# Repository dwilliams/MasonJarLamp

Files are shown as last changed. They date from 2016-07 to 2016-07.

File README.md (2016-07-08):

# MasonJarLamp
Making a board to turn a mason jar into an LED lamp

This lamp runs on 12V AC or DC.  The design is intended to be compatible with the 12V AC Garden Lighting systems available at hardware stores.



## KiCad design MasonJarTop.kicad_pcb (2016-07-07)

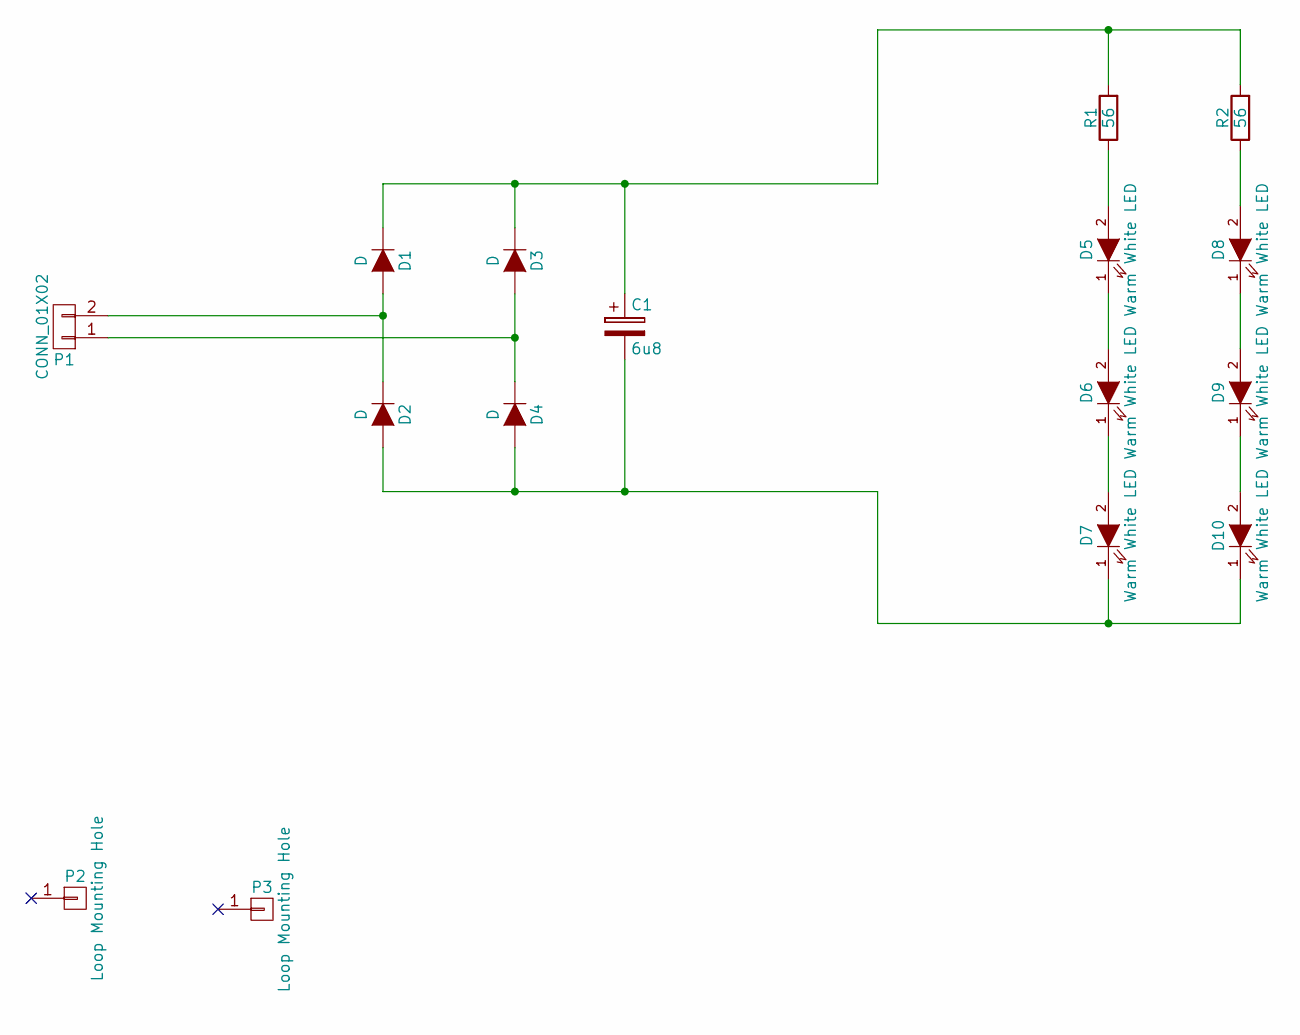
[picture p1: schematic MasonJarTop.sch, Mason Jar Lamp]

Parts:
C1: 6u8; c_elec_4x5.3; DigiKey 732-8429-1-ND
D1, D2, D3, D4: D; LED_1206; DigiKey DA2JF2300LCT-ND
D5, D6, D7, D8, D9, D10: Warm White LED; LED_1206; DigiKey 1416-1216-1-ND
P1: CONN_01X02; Pin_Header_Straight_1x02
P2, P3: Loop Mounting Hole; SolderWirePad_single_2mmDrill
R1, R2: 56; R_1206_HandSoldering; DigiKey 311-56ERCT-ND

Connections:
unnamed: C1.1, D1.1 (K), D3.1 (K), R1.2, R2.2
unnamed: C1.2, D2.2 (A), D4.2 (A), D7.1 (K), D10.1 (K)
unnamed: D1.2 (A), D2.1 (K), P1.2
unnamed: D3.2 (A), D4.1 (K), P1.1
unnamed: D5.1 (K), D6.2 (A)
unnamed: D5.2 (A), R1.1
unnamed: D6.1 (K), D7.2 (A)
unnamed: D8.1 (K), D9.2 (A)
unnamed: D8.2 (A), R2.1
unnamed: D9.1 (K), D10.2 (A)

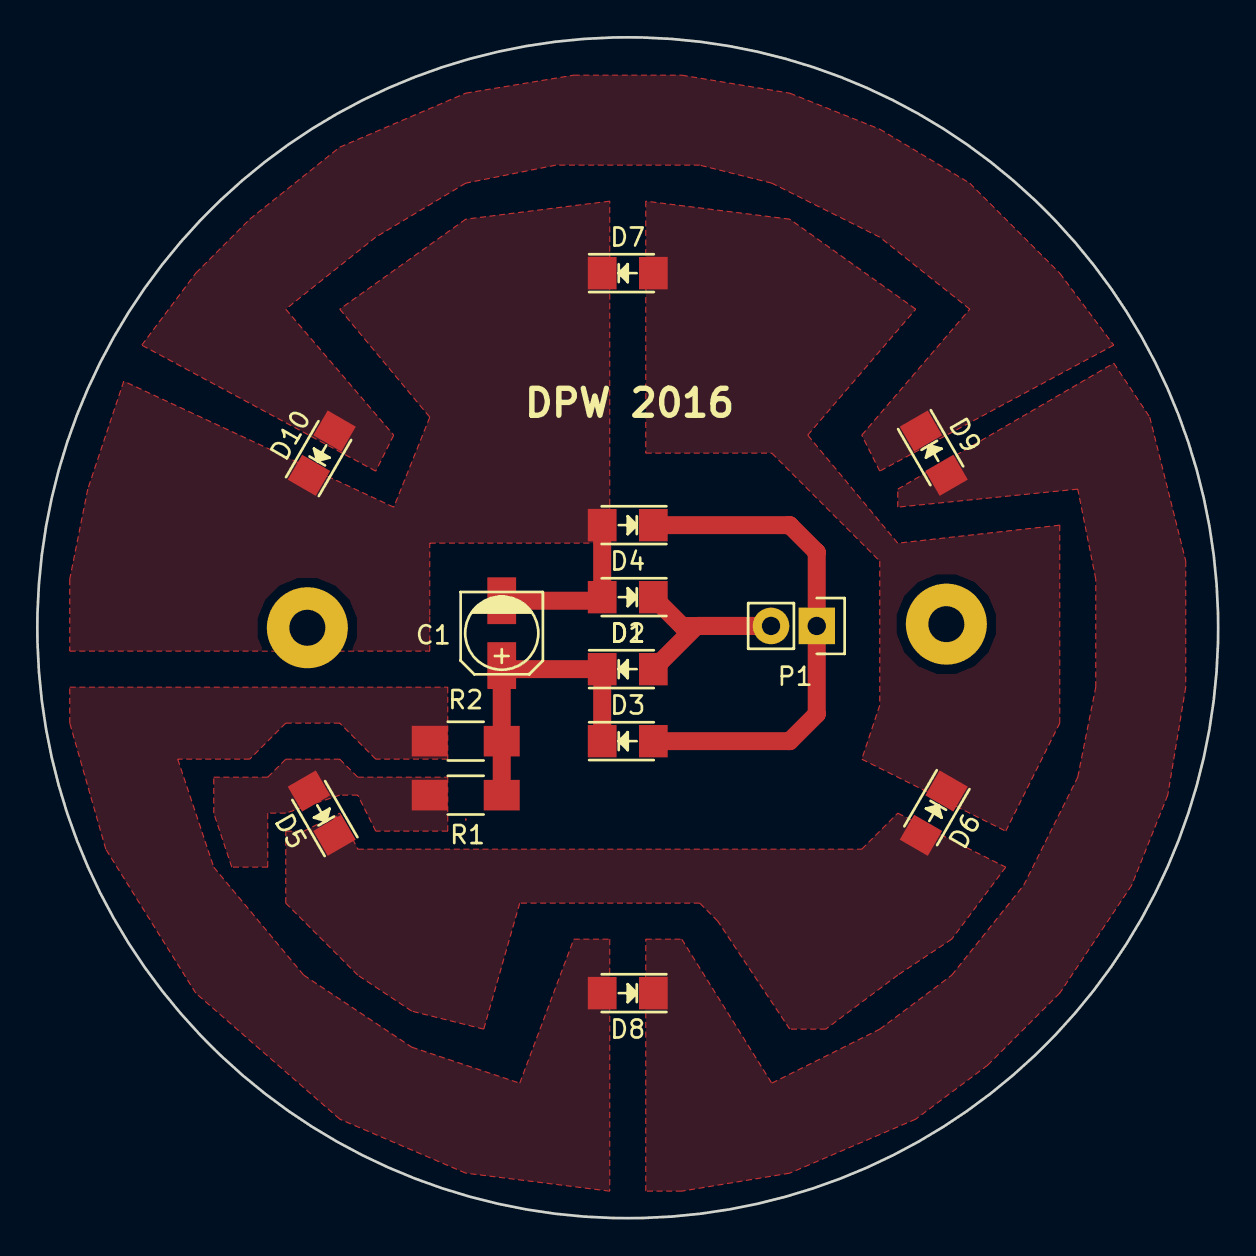
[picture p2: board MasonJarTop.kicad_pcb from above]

Board: 2 copper layers, 65.6 x 65.6 mm, 16 parts (0 on the bottom side), 10 nets.

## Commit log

2016-06-24 Adding project bits to the repo.
    [MasonJarTop.kicad_pcb, MasonJarTop.sch]
2016-06-26 Updating schematic to use discrete diodes.
    [MasonJarTop.sch]
2016-06-27 Layout done.
    [MasonJarTop.kicad_pcb, MasonJarTop.sch]
2016-06-27 Finished layout.
    [MasonJarTop.kicad_pcb]
2016-06-27 Making the copper pours solid for thermal relief from the LEDs.
    [MasonJarTop.kicad_pcb]
2016-06-27 Added BOM generation plugin (I hope).
2016-07-07 Modify schematic after testing and re-layout complete.
    [MasonJarTop.kicad_pcb, MasonJarTop.sch]
